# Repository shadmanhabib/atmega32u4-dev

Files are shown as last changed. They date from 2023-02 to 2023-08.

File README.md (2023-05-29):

# ATmega32u4-Dev
Development board designed around the ATmega32u4 AVR microcontroller in a small and compact form factor.

## Table of Contents
- [ATmega32u4-Dev](#ATmega32u4-Dev)
  - [Table of Contents](#table-of-contents)
  - [About The Project](#about-the-project)
  - [Getting Started](#getting-started)
    - [Prerequisites](#prerequisites)
    - [Installation](#installation)
  - [Usage](#usage)
  - [Changelog](#changelog)

## About The Project
PCB design, fabrication and documentation of an ATmega32u4 based microcontroller board. 

This project was started to develop a system that could be used for rapid prototyping without the use of external programmers or hardware.
The design was based around the following requirements:

1. On-board programming i.e. not require FTDI or ISP.
2. Remain compatible with Arduno Framework i.e. use Arduino Leonardo pinout.
3. Feature LiPo support.
4. Feature USB-C.

## Getting Started
To get a build this project (or parts thereof), these steps may be followed.

### Prerequisites
1. PlatformIO, Microchip Studios or Arduino IDE for code generation and upload.
2. If you want to make changes to the PCB design or would like to generate new fabrication files, an installation of KiCAD is required.

### Installation
1. Manufacture a PCB.
2. Upload code.

## Usage
Examples will be given in future iterations of this file.

_For more examples, please refer to the [Documentation](https://)_

## Changelog
All notable changes to this project will be documented in this section.

The format is based on [Keep a Changelog](https://keepachangelog.com/en/1.0.0/),
and this project attempts to adhere to [Semantic Versioning](https://semver.org/spec/v2.0.0.html).

### [v1.0.0]
#### Initial design
- ATmega32u4 based design.
- Included LiPo power and charge circuit.
- USB-C for LiPo charging, power and programming.

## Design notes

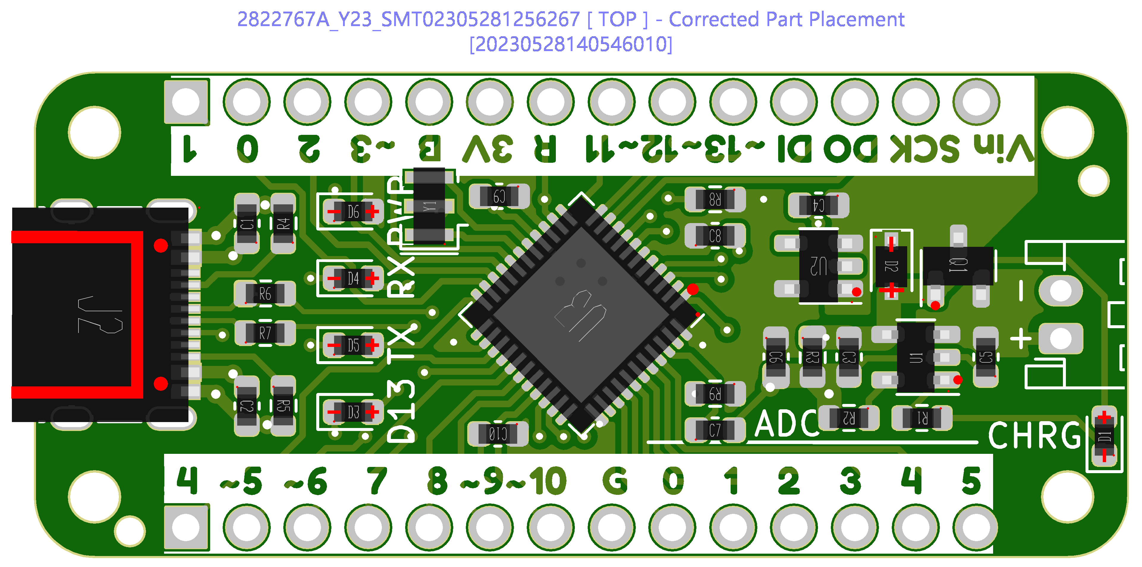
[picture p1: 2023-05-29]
hardware/documentation/Produce_DanZhi.SMT_Snapshot.Top.2822767A_Y23.SMT02305281256267.png

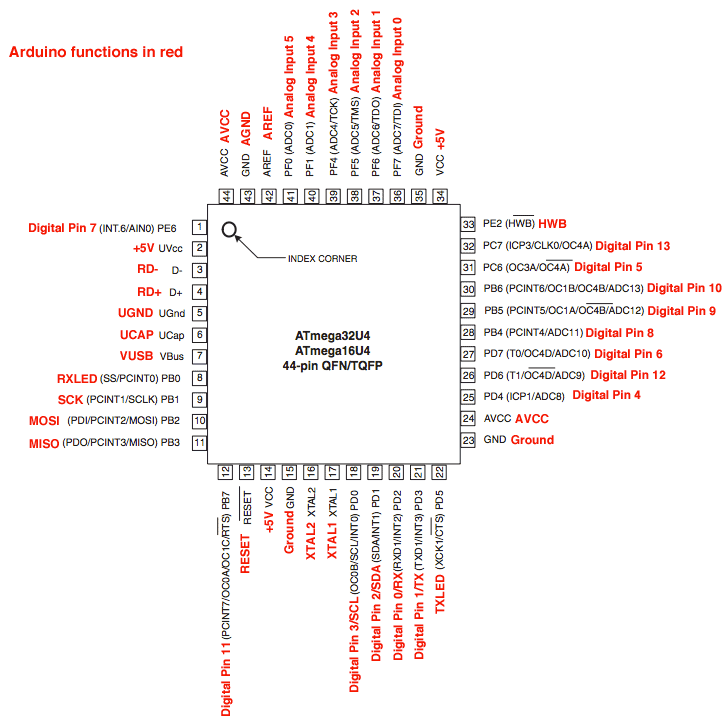
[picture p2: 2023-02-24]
documentation/Arduino-pin-mapping.png

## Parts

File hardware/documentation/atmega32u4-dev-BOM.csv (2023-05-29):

Comment | Designator | Footprint | LCSC
10uF | C1,C2 | Capacitor_SMD:C_0603_1608Metric | C96446
1uF | C3,C4,C5,C6,C8,C9 | Capacitor_SMD:C_0603_1608Metric | C15849
0.1uF | C7,C10 | Capacitor_SMD:C_0603_1608Metric | C14663
LED | D1 | LED_SMD:LED_0603_1608Metric | C2286
1N5819 | D2 | Diode_SMD:D_SOD-323 | C191023
Green LED | D3 | LED_SMD:LED_0603_1608Metric | C72043
Yellow LED | D4,D5 | LED_SMD:LED_0603_1608Metric | C72038
Blue LED | D6 | LED_SMD:LED_0603_1608Metric | C72041
USB_C_Receptacle_USB2.0 | J2 | Connector_USB:USB_C_Receptacle_Palconn_UTC16-G | C2927038
AO3401A | Q1 | Package_TO_SOT_SMD:SOT-23 | C15127
330 | R1 | Resistor_SMD:R_0603_1608Metric | C23138
2k | R2 | Resistor_SMD:R_0603_1608Metric | C22975
100k | R3 | Resistor_SMD:R_0603_1608Metric | C25803
5.1k | R4,R5 | Resistor_SMD:R_0603_1608Metric | C23186
22 | R6,R7 | Resistor_SMD:R_0603_1608Metric | C22950
10k | R8,R9 | Resistor_SMD:R_0603_1608Metric | C25804
LTC4054ES5-4.2 | U1 | Package_TO_SOT_SMD:TSOT-23-5 | C32574
AP2112K-3.3 | U2 | Package_TO_SOT_SMD:SOT-23-5 | C51118
ATmega32U4-M | U3 | Package_DFN_QFN:QFN-44-1EP_7x7mm_P0.5mm_EP5.2x5.2mm | C112161
Resonator | Y1 | Crystal:Resonator_SMD_Murata_CSTxExxV-3Pin_3.0x1.1mm | C341523

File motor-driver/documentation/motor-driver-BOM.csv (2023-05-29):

Comment | Designator | Footprint | LCSC
10uF | C1,C7,C8 | Capacitor_SMD:C_1206_3216Metric
1uF | C2 | Capacitor_SMD:C_0603_1608Metric
0.1uF | C3,C4,C5 | Capacitor_SMD:C_0603_1608Metric
1.1nF | C6 | Capacitor_SMD:C_0603_1608Metric
1N5819 | D1,D2 | Diode_SMD:D_SOD-123
SolderJumper_2_Bridged | JP1 | Jumper:SolderJumper-2_P1.3mm_Bridged_RoundedPad1.0x1.5mm
SolderJumper_2_Open | JP2,JP3 | Jumper:SolderJumper-2_P1.3mm_Open_RoundedPad1.0x1.5mm
3.3uH | L1 | Inductor_SMD:L_6.3x6.3_H3
AO3401A | Q1 | Package_TO_SOT_SMD:SOT-23
30k | R1 | Resistor_SMD:R_0603_1608Metric
130k | R2 | Resistor_SMD:R_0603_1608Metric
18.2k | R3 | Resistor_SMD:R_0603_1608Metric
100k | R4,R5 | Resistor_SMD:R_0603_1608Metric
TPS61085T | U1 | Package_SO:VSSOP-8_3.0x3.0mm_P0.65mm
DRV8835 | U2 | Package_SON:WSON-12-1EP_3x2mm_P0.5mm_EP1x2.65

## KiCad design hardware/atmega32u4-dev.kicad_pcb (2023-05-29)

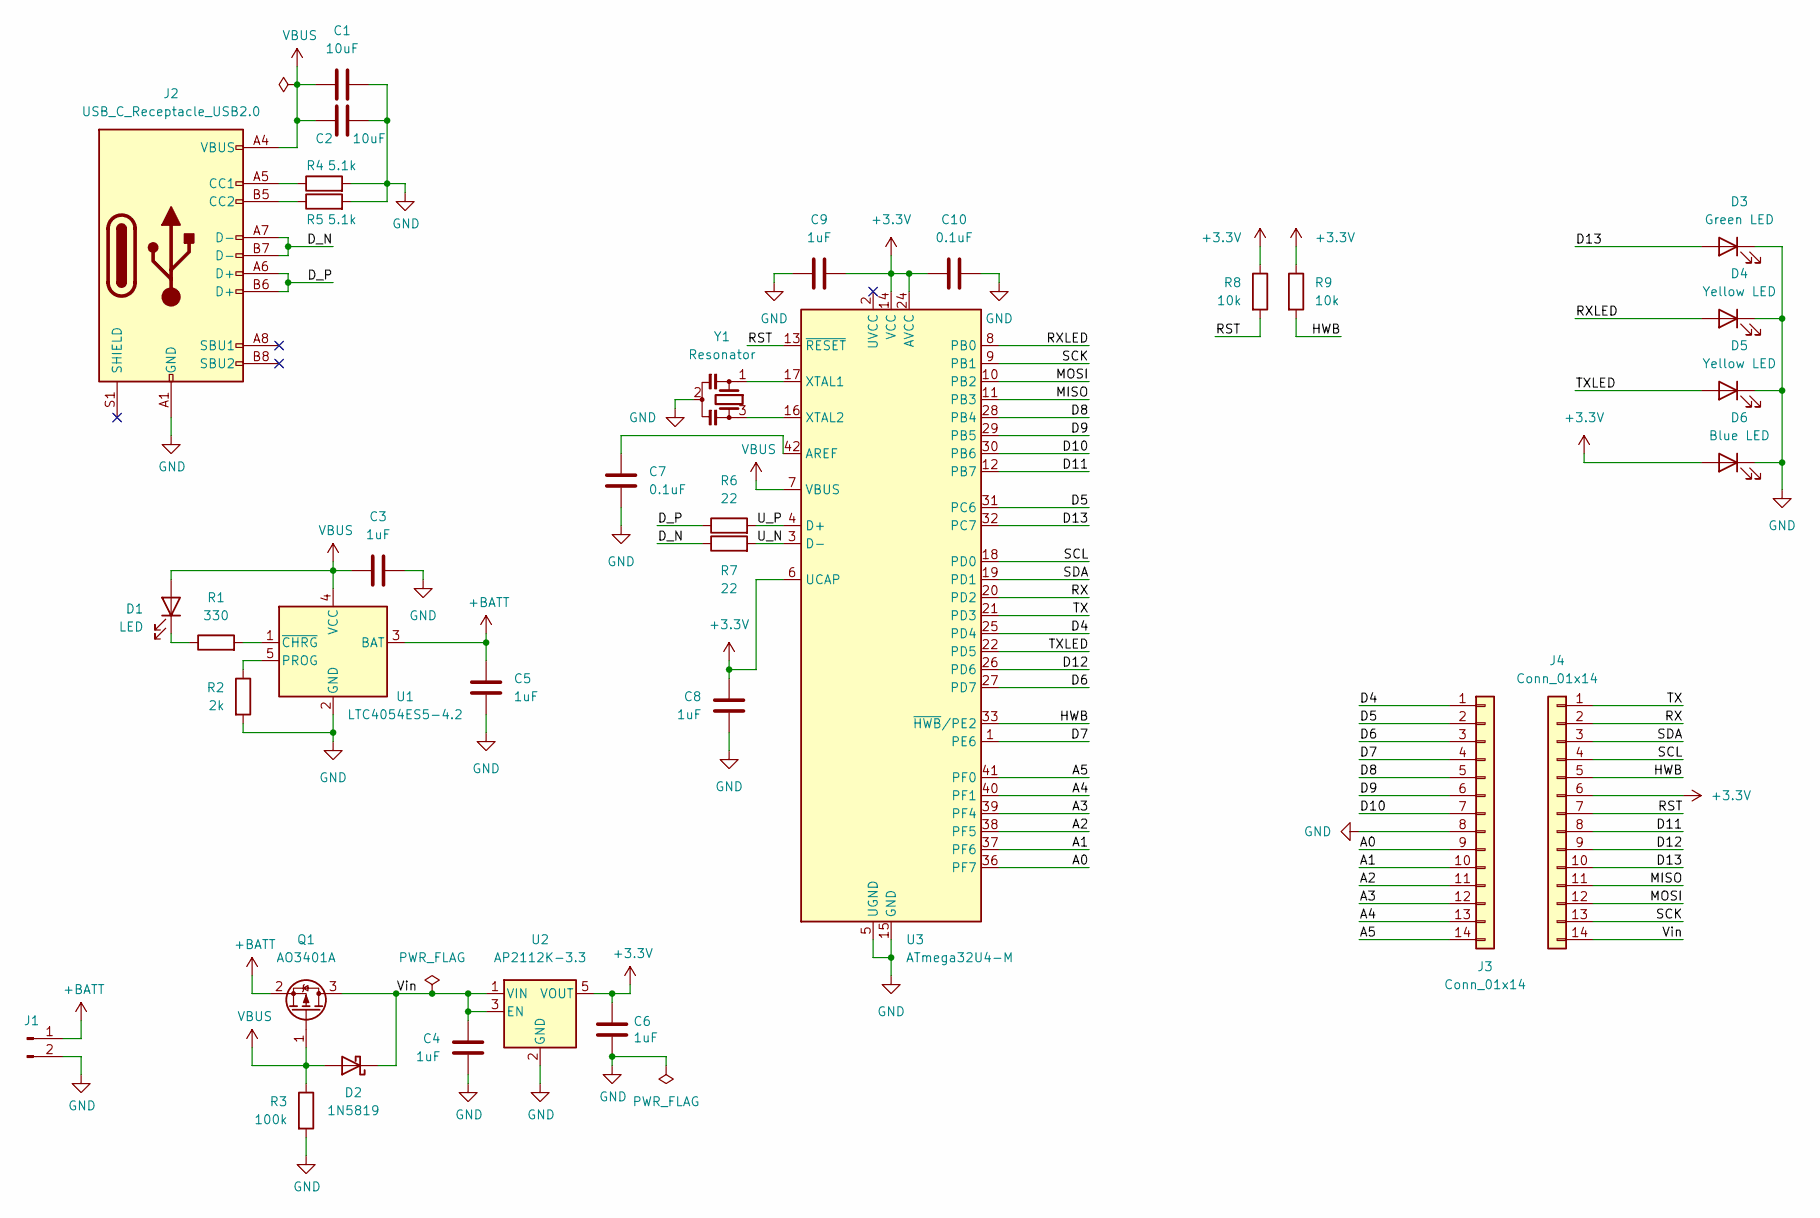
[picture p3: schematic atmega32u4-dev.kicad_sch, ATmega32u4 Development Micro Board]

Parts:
C1, C2: 10uF; C_0603_1608Metric
C3, C4, C5, C6, C8, C9: 1uF; C_0603_1608Metric
C7, C10: 0.1uF; C_0603_1608Metric
D1: LED; LED_0603_1608Metric
D2: 1N5819; D_SOD-323
D3: Green LED; LED_0603_1608Metric
D4, D5: Yellow LED; LED_0603_1608Metric
D6: Blue LED; LED_0603_1608Metric
J1: Conn_01x02_Male; JST_PH_S2B-PH-K_1x02_P2.00mm_Horizontal
J2: USB_C_Receptacle_USB2.0; USB_C_Receptacle_Palconn_UTC16-G
J3, J4: Conn_01x14; PinHeader_1x14_P2.54mm_Vertical
Q1: AO3401A; SOT-23
R1: 330; R_0603_1608Metric
R2: 2k; R_0603_1608Metric
R3: 100k; R_0603_1608Metric
R4, R5: 5.1k; R_0603_1608Metric
R6, R7: 22; R_0603_1608Metric
R8, R9: 10k; R_0603_1608Metric
U1: LTC4054ES5-4.2; TSOT-23-5
U2: AP2112K-3.3; SOT-23-5
U3: ATmega32U4-M; QFN-44-1EP_7x7mm_P0.5mm_EP5.2x5.2mm
Y1: Resonator; Resonator_SMD_Murata_CSTxExxV-3Pin_3.0x1.1mm

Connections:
+3V3: C6.1, C8.1, C9.1, C10.1, D6.2 (A), J4.6, R8.1, R9.1, U2.5 (VOUT), U3.6 (UCAP), U3.14 (VCC), U3.24 (AVCC), U3.34 (VCC), U3.44 (AVCC)
+BATT: C5.2, J1.1, Q1.2 (S), U1.3 (BAT)
/A0: J3.9, U3.36 (PF7)
/A1: J3.10, U3.37 (PF6)
/A2: J3.11, U3.38 (PF5)
/A3: J3.12, U3.39 (PF4)
/A4: J3.13, U3.40 (PF1)
/A5: J3.14, U3.41 (PF0)
/D4: J3.1, U3.25 (PD4)
/D5: J3.2, U3.31 (PC6)
/D6: J3.3, U3.27 (PD7)
/D7: J3.4, U3.1 (PE6)
/D8: J3.5, U3.28 (PB4)
/D9: J3.6, U3.29 (PB5)
/D10: J3.7, U3.30 (PB6)
/D11: J4.8, U3.12 (PB7)
/D12: J4.9, U3.26 (PD6)
/D13: D3.2 (A), J4.10, U3.32 (PC7)
/D_N: J2.A7 (D-), J2.B7 (D-), R7.1
/D_P: J2.A6 (D+), J2.B6 (D+), R6.1
/HWB: J4.5, R9.2, U3.33 (~HWB/PE2)
/MISO: J4.11, U3.11 (PB3)
/MOSI: J4.12, U3.10 (PB2)
/RST: J4.7, R8.2, U3.13 (~RESET)
/RX: J4.2, U3.20 (PD2)
/RXLED: D4.2 (A), U3.8 (PB0)
/SCK: J4.13, U3.9 (PB1)
/SCL: J4.4, U3.18 (PD0)
/SDA: J4.3, U3.19 (PD1)
/TX: J4.1, U3.21 (PD3)
/TXLED: D5.2 (A), U3.22 (PD5)
/U_N: R7.2, U3.3 (D-)
/U_P: R6.2, U3.4 (D+)
/Vin: C4.1, D2.1 (K), J4.14, Q1.3 (D), U2.1 (VIN), U2.3 (EN)
GND: C1.2, C2.2, C3.2, C4.2, C5.1, C6.2, C7.2, C8.2, C9.2, C10.2, D3.1 (K), D4.1 (K), D5.1 (K), D6.1 (K), J1.2, J2.A1 (GND), J2.A12 (GND), J2.B1 (GND), J2.B12 (GND), J3.8, R2.2, R3.2, R4.2, R5.2, U1.2 (GND), U2.2 (GND), U3.5 (UGND), U3.15 (GND), U3.23 (GND), U3.35 (GND), U3.43 (GND), U3.45 (GND), Y1.2
unnamed: C7.1, U3.42 (AREF)
unnamed: D1.1 (K), R1.1
unnamed: J2.A5 (CC1), R4.1
unnamed: J2.B5 (CC2), R5.1
unnamed: R1.2, U1.1 (~CHRG)
unnamed: R2.1, U1.5 (PROG)
unnamed: U3.16 (XTAL2), Y1.3
unnamed: U3.17 (XTAL1), Y1.1
VBUS: C1.1, C2.1, C3.1, D1.2 (A), D2.2 (A), J2.A4 (VBUS), J2.A9 (VBUS), J2.B4 (VBUS), J2.B9 (VBUS), Q1.1 (G), R3.1, U1.4 (VCC), U3.7 (VBUS)

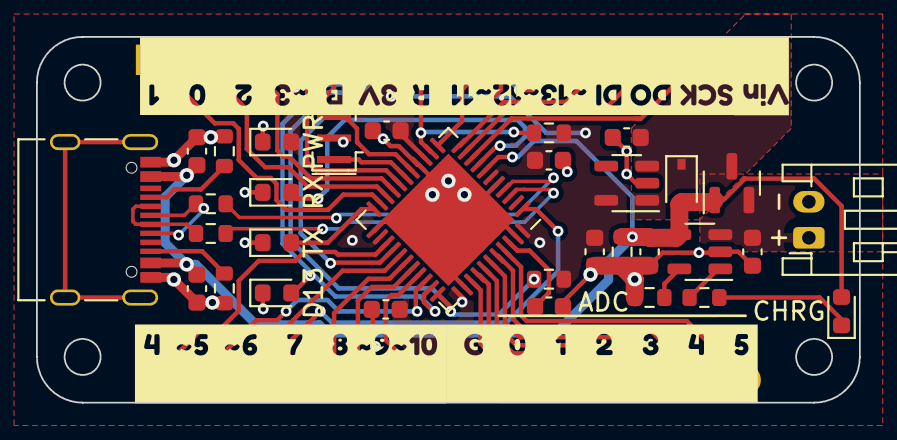
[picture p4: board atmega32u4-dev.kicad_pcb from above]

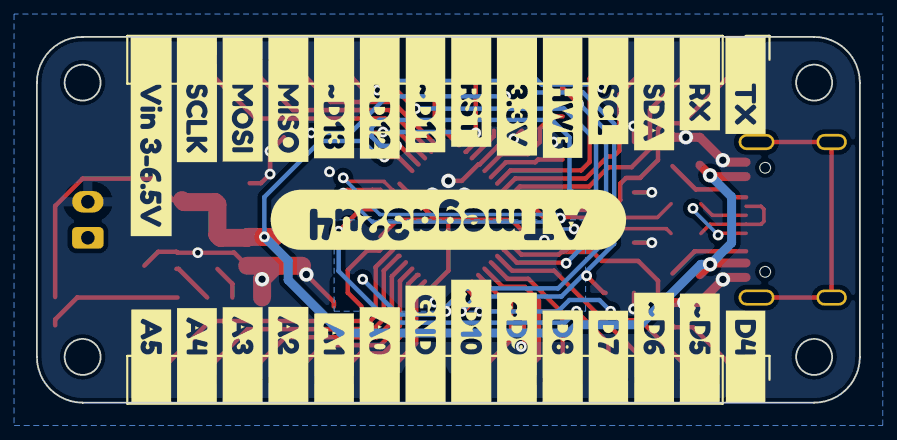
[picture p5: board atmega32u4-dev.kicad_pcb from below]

Board: 2 copper layers, 45.7 x 20.3 mm, 70 parts (31 on the bottom side), 44 nets.

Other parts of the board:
kibuzzard-63FC0A8C: G***; kibuzzard-63FC0A8C
kibuzzard-63FC0C67: G***; kibuzzard-63FC0C67
kibuzzard-63FC0D8E: G***; kibuzzard-63FC0D8E
kibuzzard-63FC0E25: G***; kibuzzard-63FC0E25
kibuzzard-63FC1D99: G***; kibuzzard-63FC1D99
kibuzzard-63FC1DA9: G***; kibuzzard-63FC1DA9
kibuzzard-63FC1DB5: G***; kibuzzard-63FC1DB5
kibuzzard-63FC1DBD: G***; kibuzzard-63FC1DBD
kibuzzard-63FC1DF3: G***; kibuzzard-63FC1DF3
kibuzzard-63FC1EB5: G***; kibuzzard-63FC1EB5
kibuzzard-63FC1EBD: G***; kibuzzard-63FC1EBD
kibuzzard-63FC1EC6: G***; kibuzzard-63FC1EC6
kibuzzard-63FC1F6E: G***; kibuzzard-63FC1F6E
kibuzzard-63FC1F7A: G***; kibuzzard-63FC1F7A
kibuzzard-63FC1F52: G***; kibuzzard-63FC1F52
kibuzzard-63FC1F60: G***; kibuzzard-63FC1F60
kibuzzard-63FC1F68: G***; kibuzzard-63FC1F68
kibuzzard-63FC1F81: G***; kibuzzard-63FC1F81
kibuzzard-63FC1FBE: G***; kibuzzard-63FC1FBE
kibuzzard-63FC1FCA: G***; kibuzzard-63FC1FCA
kibuzzard-63FC1FD1: G***; kibuzzard-63FC1FD1
kibuzzard-63FC1FE1: G***; kibuzzard-63FC1FE1
kibuzzard-63FC1FE8: G***; kibuzzard-63FC1FE8
kibuzzard-63FC1FF3: G***; kibuzzard-63FC1FF3
kibuzzard-63FC1FFB: G***; kibuzzard-63FC1FFB
kibuzzard-63FC10C2: G***; kibuzzard-63FC10C2
kibuzzard-63FC10EF: G***; kibuzzard-63FC10EF
kibuzzard-63FC11B0: G***; kibuzzard-63FC11B0
kibuzzard-63FC11D2: G***; kibuzzard-63FC11D2
kibuzzard-63FC11DC: G***; kibuzzard-63FC11DC
kibuzzard-63FC11E2: G***; kibuzzard-63FC11E2
kibuzzard-63FC11F1: G***; kibuzzard-63FC11F1
kibuzzard-63FC11F9: G***; kibuzzard-63FC11F9
kibuzzard-63FC107B: G***; kibuzzard-63FC107B
kibuzzard-63FC2005: G***; kibuzzard-63FC2005
kibuzzard-63FC2462: G***; kibuzzard-63FC2462

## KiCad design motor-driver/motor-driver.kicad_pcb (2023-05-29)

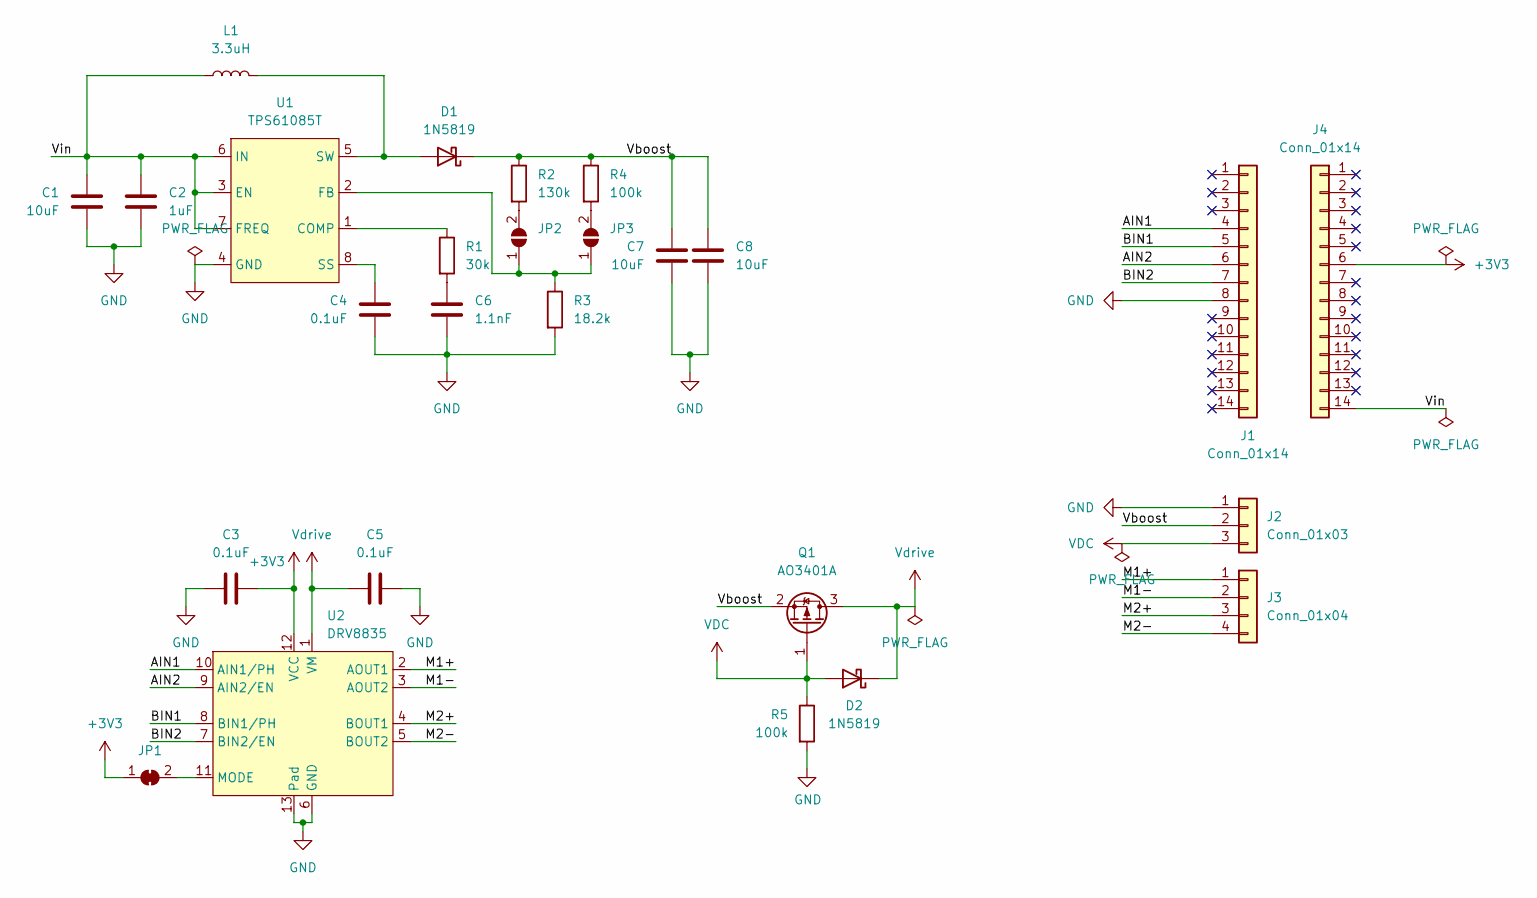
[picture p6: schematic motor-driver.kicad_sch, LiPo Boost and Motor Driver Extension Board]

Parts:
C1, C7, C8: 10uF; C_1206_3216Metric
C2: 1uF; C_0603_1608Metric
C3, C4, C5: 0.1uF; C_0603_1608Metric
C6: 1.1nF; C_0603_1608Metric
D1, D2: 1N5819; D_SOD-123
J1, J4: Conn_01x14; PinHeader_1x14_P2.54mm_Vertical
J2: Conn_01x03; PinHeader_1x03_P2.54mm_Vertical
J3: Conn_01x04; PinHeader_1x04_P2.54mm_Vertical
JP1: SolderJumper_2_Bridged; SolderJumper-2_P1.3mm_Bridged_RoundedPad1.0x1.5mm
JP2, JP3: SolderJumper_2_Open; SolderJumper-2_P1.3mm_Open_RoundedPad1.0x1.5mm
L1: 3.3uH; L_6.3x6.3_H3
Q1: AO3401A; SOT-23
R1: 30k; R_0603_1608Metric
R2: 130k; R_0603_1608Metric
R3: 18.2k; R_0603_1608Metric
R4, R5: 100k; R_0603_1608Metric
U1: TPS61085T; VSSOP-8_3.0x3.0mm_P0.65mm
U2: DRV8835; WSON-12-1EP_3x2mm_P0.5mm_EP1x2.65

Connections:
+3V3: C3.2, J4.6, JP1.1 (A), U2.12 (VCC)
/AIN1: J1.4, U2.10 (AIN1/PH)
/AIN2: J1.6, U2.9 (AIN2/EN)
/BIN1: J1.5, U2.8 (BIN1/PH)
/BIN2: J1.7, U2.7 (BIN2/EN)
/M1+: J3.1, U2.2 (AOUT1)
/M1-: J3.2, U2.3 (AOUT2)
/M2+: J3.3, U2.4 (BOUT1)
/M2-: J3.4, U2.5 (BOUT2)
/Vboost: C7.1, C8.1, D1.1 (K), J2.2, Q1.2 (S), R2.1, R4.1
/Vin: C1.1, C2.1, J4.14, L1.1, U1.3 (EN), U1.6 (IN), U1.7 (FREQ)
GND: C1.2, C2.2, C3.1, C4.2, C5.2, C6.2, C7.2, C8.2, J1.8, J2.1, R3.2, R5.2, U1.4 (GND), U2.6 (GND), U2.13 (Pad)
unnamed: C4.1, U1.8 (SS)
unnamed: C6.1, R1.2
unnamed: D1.2 (A), L1.2, U1.5 (SW)
unnamed: JP1.2 (B), U2.11 (MODE)
unnamed: JP2.1 (A), JP3.1 (A), R3.1, U1.2 (FB)
unnamed: JP2.2 (B), R2.2
unnamed: JP3.2 (B), R4.2
unnamed: R1.1, U1.1 (COMP)
VDC: D2.2 (A), J2.3, Q1.1 (G), R5.1
Vdrive: C5.1, D2.1 (K), Q1.3 (D), U2.1 (VM)

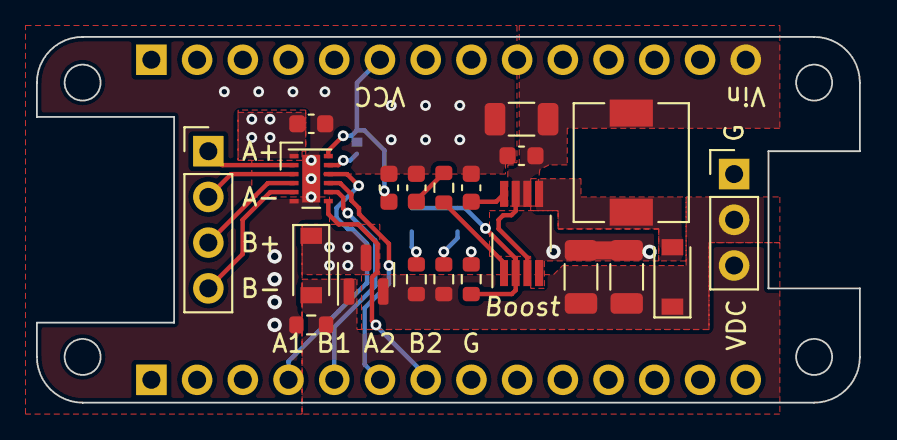
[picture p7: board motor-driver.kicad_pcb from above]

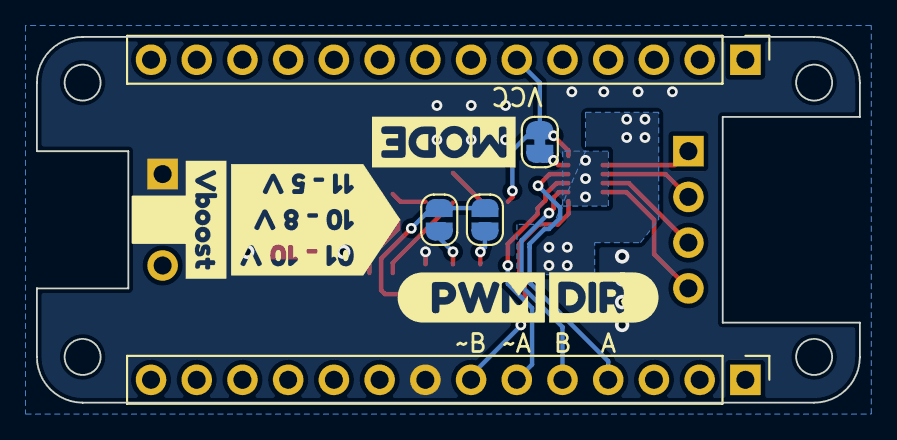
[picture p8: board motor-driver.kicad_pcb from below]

Board: 2 copper layers, 45.7 x 20.3 mm, 31 parts (10 on the bottom side), 22 nets.

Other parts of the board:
kibuzzard-6471BDC6: G***; kibuzzard-6471BDC6
kibuzzard-6471BDE7: G***; kibuzzard-6471BDE7
kibuzzard-6471BF11: G***; kibuzzard-6471BF11
kibuzzard-6471C20C: G***; kibuzzard-6471C20C
kibuzzard-6471C159: G***; kibuzzard-6471C159

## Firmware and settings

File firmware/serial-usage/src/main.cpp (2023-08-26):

#include <Arduino.h>

void setup() {
  // put your setup code here, to run once:
  Serial.begin(9600);

  while(!Serial) {
    // Do nothing
    delay(1000);
  }

  Serial.println("This is the setup...");
}

void loop() {
  // put your main code here, to run repeatedly:
  Serial.println("Hello World!");
  delay(1000);
}

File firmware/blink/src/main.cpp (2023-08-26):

#include <Arduino.h>

#define LED_PIN 13

// put function declarations here:
int myFunction(int, int);

void setup() {
  // put your setup code here, to run once:
  pinMode(LED_PIN, OUTPUT);

}

void loop() {
  // put your main code here, to run repeatedly:
  digitalWrite(LED_PIN, HIGH);
  delay(1000);
  digitalWrite(LED_PIN, LOW);
  delay(1000);
}

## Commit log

2023-02-22 Initial commit
    Setup folder structure, KiCAD files and README.
    [atmega32u4-dev.kicad_pcb, atmega32u4-dev.kicad_sch]
2023-02-24 Schematic first draft
    First iteration of dev board schematic.
    [atmega32u4-dev.kicad_sch]
2023-02-27 Completed PCB layout
    Completed PCB layout for manufacture.
    [atmega32u4-dev.kicad_pcb, atmega32u4-dev.kicad_sch]
2023-05-27 Completed v1.0.0
    Added files for LiPo boost and motor driver board. Completed schematic and layout.
    [atmega32u4-dev.kicad_pcb, atmega32u4-dev.kicad_sch, motor-driver.kicad_pcb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]
2023-05-29 Generated BOM and fabrication files for v1.0.0 boards.
    [atmega32u4-dev-BOM.csv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]
